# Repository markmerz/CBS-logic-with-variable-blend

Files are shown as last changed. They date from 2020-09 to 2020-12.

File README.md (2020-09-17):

# CBS-logic-with-variable-blend

My attempt at SQ decoder with MC1312, MC1314 and MC1315 chips.

Beware, I assembled the board but it didn't work right. It's still hooked up to meters in my bench, waiting for an inspiration. You can use the zip file for ordering your own boards if you feeling lucky.

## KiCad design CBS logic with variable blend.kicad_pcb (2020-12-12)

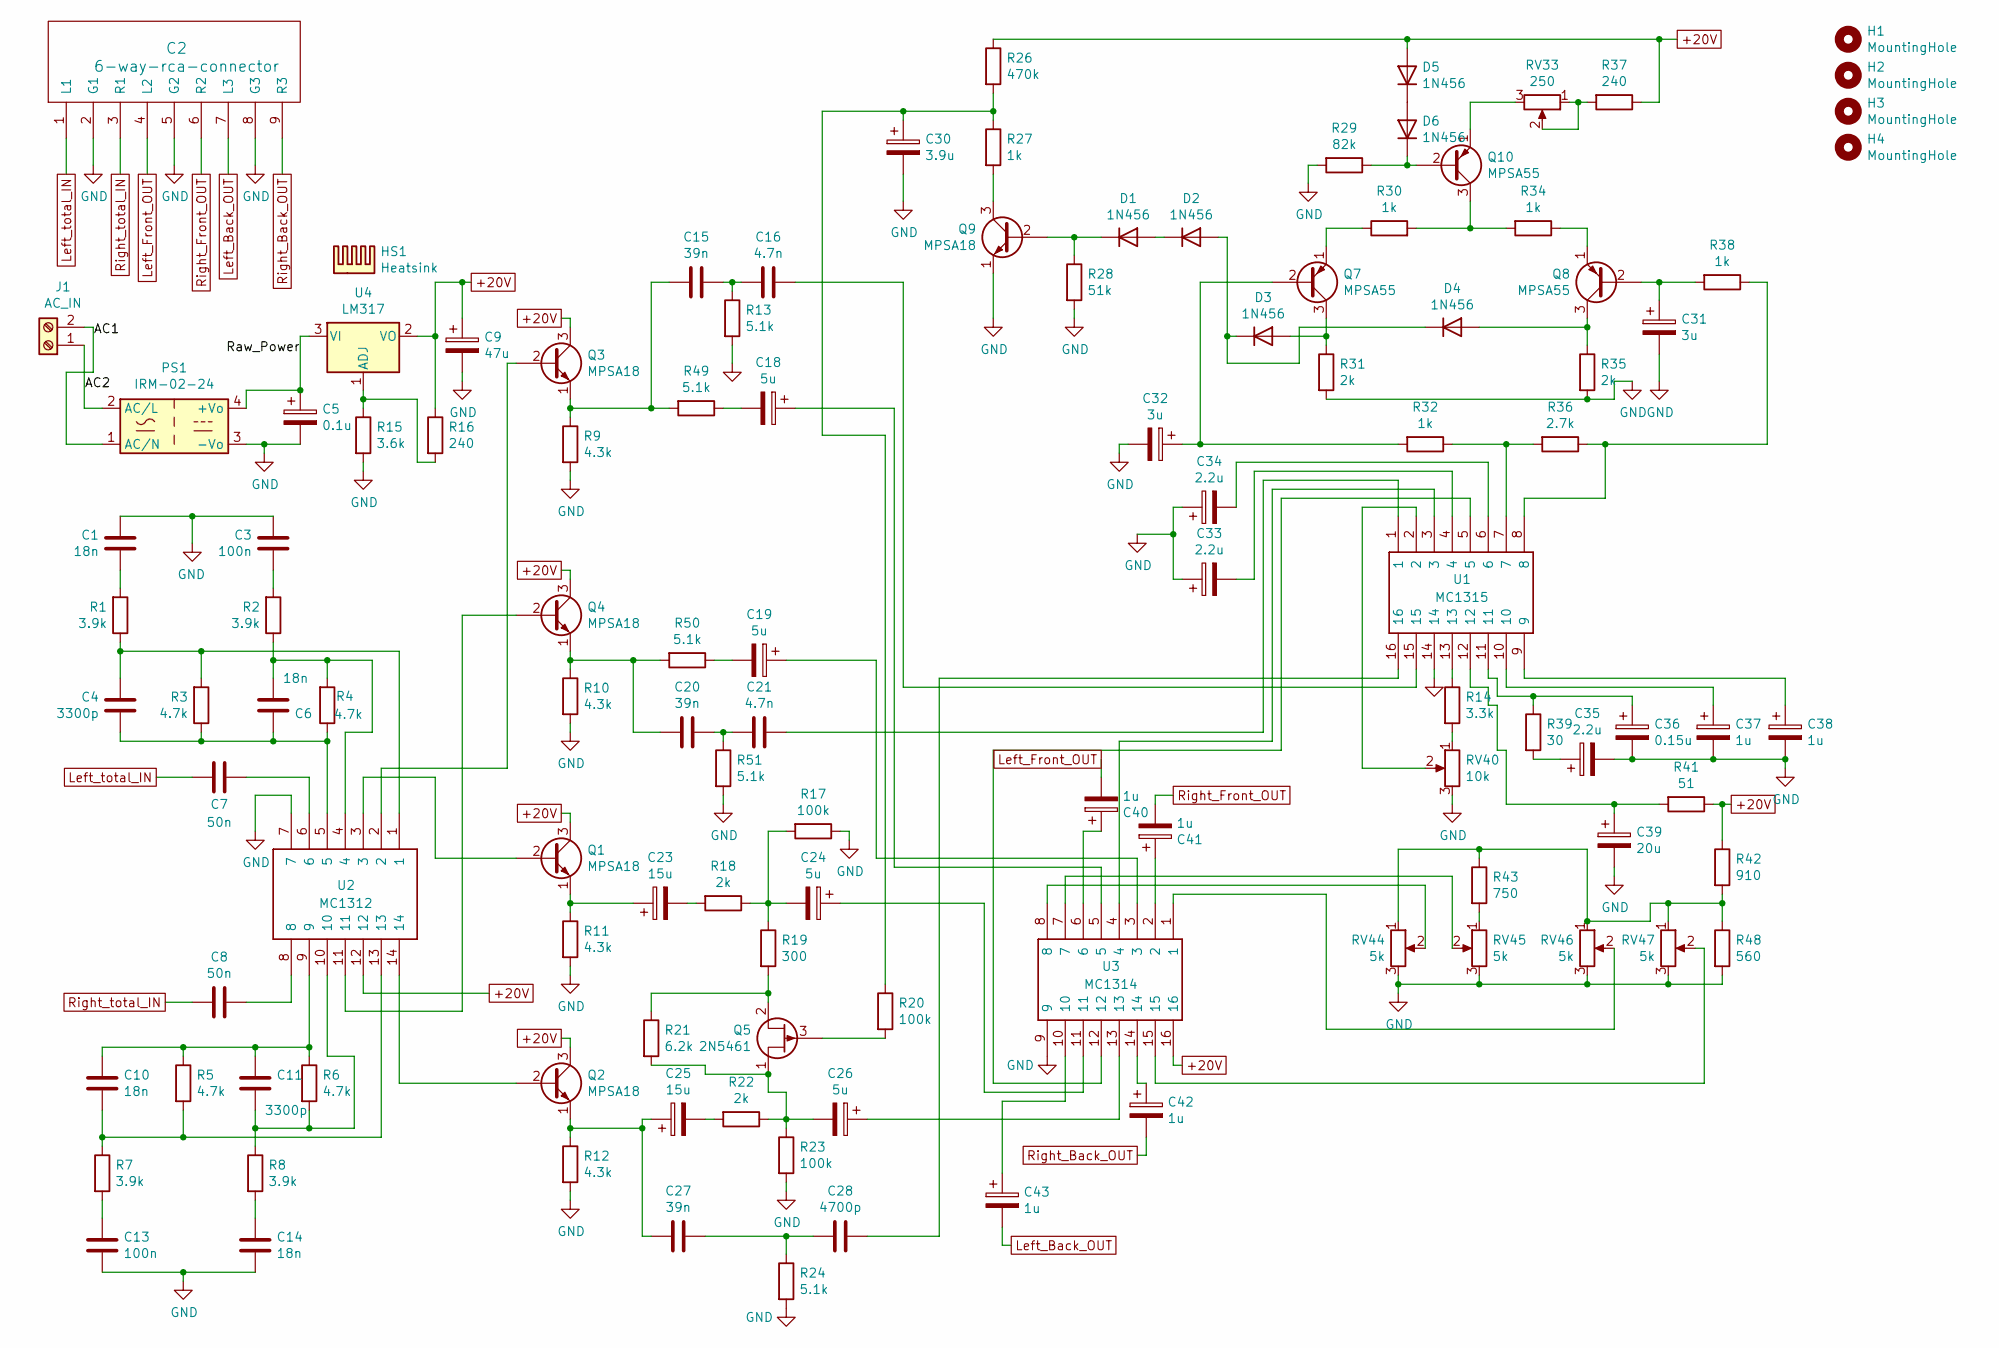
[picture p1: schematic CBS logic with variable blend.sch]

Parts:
C1, C6, C10, C14: 18n; C_Disc_D5.0mm_W2.5mm_P2.50mm
C2: 6-way-rca-connector; 6-way-rca-connector-on-edge
C3, C13: 100n; C_Disc_D5.0mm_W2.5mm_P2.50mm
C4, C11: 3300p; C_Disc_D5.0mm_W2.5mm_P2.50mm
C5: 0.1u; CP_Radial_D4.0mm_P2.00mm
C7, C8: 50n; C_Disc_D5.0mm_W2.5mm_P2.50mm
C9: 47u; CP_Radial_D4.0mm_P2.00mm
C15, C20, C27: 39n; C_Disc_D5.0mm_W2.5mm_P2.50mm
C16, C21: 4.7n; C_Disc_D5.0mm_W2.5mm_P2.50mm
C18, C19, C24, C26: 5u; CP_Radial_D4.0mm_P2.00mm
C23, C25: 15u; CP_Radial_D4.0mm_P2.00mm
C28: 4700p; C_Disc_D5.0mm_W2.5mm_P2.50mm
C30: 3.9u; CP_Radial_D4.0mm_P2.00mm
C31, C32: 3u; CP_Radial_D4.0mm_P2.00mm
C33, C34, C35: 2.2u; CP_Radial_D4.0mm_P2.00mm
C36: 0.15u; CP_Radial_D4.0mm_P2.00mm
C37, C38, C40, C41, C42, C43: 1u; CP_Radial_D4.0mm_P2.00mm
C39: 20u; CP_Radial_D4.0mm_P2.00mm
D1, D2, D3, D4, D5, D6: 1N456; D_DO-35_SOD27_P5.08mm_Vertical_KathodeUp
H1, H2, H3, H4: MountingHole; MountingHole_3.2mm_M3
HS1: Heatsink; to220_heatsink
J1: AC_IN; SCREWTERMINAL-5MM-2
PS1: IRM-02-24; Converter_ACDC_MeanWell_IRM-02-xx_THT
Q1, Q2, Q3, Q4, Q9: MPSA18; TO-92_Inline
Q5: 2N5461; TO-92_Inline
Q7, Q8, Q10: MPSA55; TO-92_Inline
R1, R2, R7, R8: 3.9k; R_Axial_DIN0207_L6.3mm_D2.5mm_P2.54mm_Vertical
R3, R4, R5, R6: 4.7k; R_Axial_DIN0207_L6.3mm_D2.5mm_P2.54mm_Vertical
R9, R10, R11, R12: 4.3k; R_Axial_DIN0207_L6.3mm_D2.5mm_P2.54mm_Vertical
R13, R24, R49, R50, R51: 5.1k; R_Axial_DIN0207_L6.3mm_D2.5mm_P2.54mm_Vertical
R14: 3.3k; R_Axial_DIN0207_L6.3mm_D2.5mm_P2.54mm_Vertical
R15: 3.6k; R_Axial_DIN0207_L6.3mm_D2.5mm_P2.54mm_Vertical
R16, R37: 240; R_Axial_DIN0207_L6.3mm_D2.5mm_P2.54mm_Vertical
R17, R20, R23: 100k; R_Axial_DIN0207_L6.3mm_D2.5mm_P2.54mm_Vertical
R18, R22, R31, R35: 2k; R_Axial_DIN0207_L6.3mm_D2.5mm_P2.54mm_Vertical
R19: 300; R_Axial_DIN0207_L6.3mm_D2.5mm_P2.54mm_Vertical
R21: 6.2k; R_Axial_DIN0207_L6.3mm_D2.5mm_P2.54mm_Vertical
R26: 470k; R_Axial_DIN0207_L6.3mm_D2.5mm_P2.54mm_Vertical
R27, R30, R32, R34, R38: 1k; R_Axial_DIN0207_L6.3mm_D2.5mm_P2.54mm_Vertical
R28: 51k; R_Axial_DIN0207_L6.3mm_D2.5mm_P2.54mm_Vertical
R29: 82k; R_Axial_DIN0207_L6.3mm_D2.5mm_P2.54mm_Vertical
R36: 2.7k; R_Axial_DIN0207_L6.3mm_D2.5mm_P2.54mm_Vertical
R39: 30; R_Axial_DIN0207_L6.3mm_D2.5mm_P2.54mm_Vertical
R41: 51; R_Axial_DIN0207_L6.3mm_D2.5mm_P2.54mm_Vertical
R42: 910; R_Axial_DIN0207_L6.3mm_D2.5mm_P2.54mm_Vertical
R43: 750; R_Axial_DIN0207_L6.3mm_D2.5mm_P2.54mm_Vertical
R48: 560; R_Axial_DIN0207_L6.3mm_D2.5mm_P2.54mm_Vertical
RV33: 250; Potentiometer_Bourns_3296W_Vertical
RV40: 10k; Potentiometer_Bourns_3296W_Vertical
RV44, RV45, RV46, RV47: 5k; Potentiometer_Bourns_3296W_Vertical
U1: MC1315; DIP-16_W7.62mm
U2: MC1312; DIP-14_W7.62mm
U3: MC1314; DIP-16_W7.62mm
U4: LM317; TO-220-3_Vertical

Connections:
+20V: C9.1, D5.2 (A), Q1.3 (C), Q2.3 (C), Q3.3 (C), Q4.3 (C), R16.1, R26.1, R37.1, R41.1, R42.1, U2.12, U3.16, U4.2 (VO)
/AC1: J1.2, PS1.1 (AC/N)
/AC2: J1.1, PS1.2 (AC/L)
/Raw_Power: C5.1, PS1.4 (+Vo), U4.3 (VI)
GND: C1.2, C2.2 (G1), C2.5 (G2), C2.8 (G3), C3.2, C5.2, C9.2, C13.2, C14.2, C30.2, C31.2, C32.2, C33.1, C34.1, C35.2, C36.2, C37.2, C38.2, C39.2, PS1.3 (-Vo), Q9.1 (E), R9.2, R10.2, R11.2, R12.2, R13.2, R15.2, R17.1, R23.2, R24.2, R28.2, R29.2, R31.2, R35.2, R48.2, R51.2, RV40.3, RV44.3, RV45.3, RV46.3, RV47.3, U1.14, U2.7, U3.9
Left_Back_OUT: C2.7 (L3), C43.2
Left_Front_OUT: C2.4 (L2), C40.2
Left_total_IN: C2.1 (L1), C7.2
unnamed: C1.1, R1.2
unnamed: C3.1, R2.2
unnamed: C4.1, C6.1, R3.1, R4.1, U2.5
unnamed: C4.2, R1.1, R3.2, U2.1
unnamed: C6.2, R2.1, R4.2, U2.4
unnamed: C7.1, U2.6
unnamed: C8.1, U2.8
unnamed: C10.1, C11.1, R5.1, R6.1, U2.9
unnamed: C10.2, R5.2, R7.1, U2.13
unnamed: C11.2, R6.2, R8.1, U2.10
unnamed: C13.1, R7.2
unnamed: C14.1, R8.2
unnamed: C15.1, C16.2, R13.1
unnamed: C15.2, Q3.1 (E), R9.1, R49.2
unnamed: C16.1, U1.15
unnamed: C18.1, U3.5
unnamed: C18.2, R49.1
unnamed: C19.1, U3.3
unnamed: C19.2, R50.1
unnamed: C20.1, Q4.1 (E), R10.1, R50.2
unnamed: C20.2, C21.2, R51.1
unnamed: C21.1, U1.1
unnamed: C23.1, Q1.1 (E), R11.1
unnamed: C23.2, R18.2
unnamed: C24.1, U3.11
unnamed: C24.2, R17.2, R18.1, R19.1
unnamed: C25.1, C27.2, Q2.1 (E), R12.1
unnamed: C25.2, R22.2
unnamed: C26.1, U3.13
unnamed: C26.2, Q5.1 (S), R21.2, R22.1, R23.1
unnamed: C27.1, C28.2, R24.1
unnamed: C28.1, U1.16
unnamed: C30.1, R20.1, R26.2, R27.1
unnamed: C31.1, Q8.2 (B), R38.2
unnamed: C32.1, Q7.2 (B), R32.2
unnamed: C33.2, U1.4
unnamed: C34.2, U1.6
unnamed: C35.1, R39.2
unnamed: C36.1, R39.1, U1.11
unnamed: C37.1, U1.10
unnamed: C38.1, U1.9
unnamed: C39.1, R41.2, U1.12
unnamed: C40.1, U3.6
unnamed: C41.1, U3.2
unnamed: C42.1, U3.14
unnamed: C43.1, U3.10
unnamed: D1.1 (K), Q9.2 (B), R28.1
unnamed: D1.2 (A), D2.1 (K)
unnamed: D2.2 (A), D3.1 (K), D4.1 (K)
unnamed: D3.2 (A), Q7.3 (C), R31.1
unnamed: D4.2 (A), Q8.3 (C), R35.1
unnamed: D5.1 (K), D6.2 (A)
unnamed: D6.1 (K), Q10.2 (B), R29.1
unnamed: Q1.2 (B), U2.3
unnamed: Q2.2 (B), U2.14
unnamed: Q3.2 (B), U2.2
unnamed: Q4.2 (B), U2.11
unnamed: Q5.2 (D), R19.2, R21.1
unnamed: Q5.3 (G), R20.2
unnamed: Q7.1 (E), R30.1
unnamed: Q8.1 (E), R34.1
unnamed: Q9.3 (C), R27.2
unnamed: Q10.1 (E), RV33.3
unnamed: Q10.3 (C), R30.2, R34.2
unnamed: R14.1, U1.13
unnamed: R14.2, RV40.1
unnamed: R15.1, R16.2, U4.1 (ADJ)
unnamed: R32.1, R36.2, U1.7
unnamed: R36.1, R38.1, U1.8
unnamed: R37.2, RV33.1, RV33.2
unnamed: R42.2, R43.1, R48.1, RV44.1, RV46.1, RV47.1
unnamed: R43.2, RV45.1
unnamed: RV40.2, U1.2
unnamed: RV44.2, U3.8
unnamed: RV45.2, U3.7
unnamed: RV46.2, U3.1
unnamed: RV47.2, U3.15
unnamed: U1.3, U3.4
unnamed: U1.5, U3.12
Right_Back_OUT: C2.9 (R3), C42.2
Right_Front_OUT: C2.6 (R2), C41.2
Right_total_IN: C2.3 (R1), C8.2

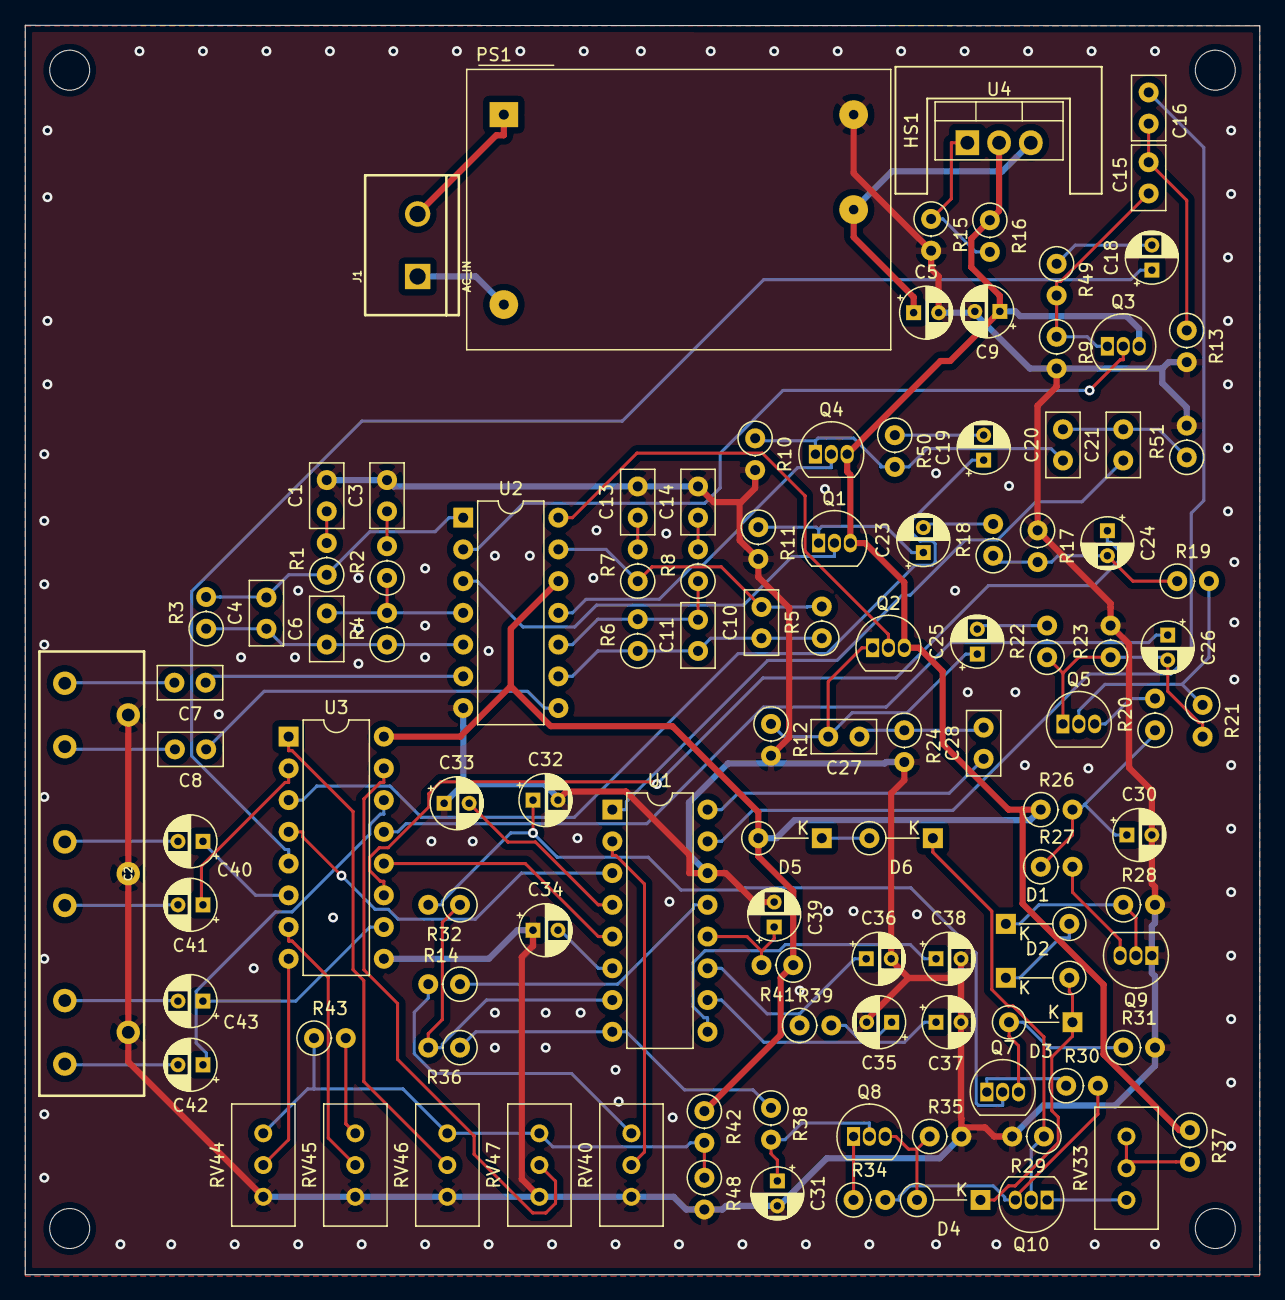
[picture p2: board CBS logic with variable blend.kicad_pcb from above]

Board: 2 copper layers, 98.8 x 100.0 mm, 115 parts (0 on the bottom side), 90 nets.
